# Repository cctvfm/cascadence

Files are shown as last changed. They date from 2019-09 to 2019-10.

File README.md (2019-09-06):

# cascadence
Cascadence is a low-cost eurorack-compatible Arduino development platform developed with the Modular Seattle Team.

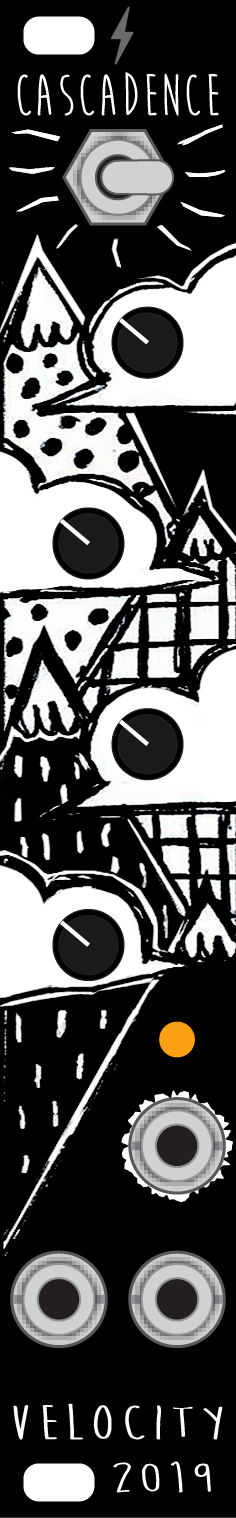
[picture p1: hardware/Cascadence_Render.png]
render


`/hardware` contains the board and panel files

`/firmware` contains the released firmwares available. You can upload new firmwares using Arduino

`/software` contains the files and instructions needed to get Cascadence working with Arduino

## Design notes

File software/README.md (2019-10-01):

# Software

This section is everything you need to upload new firmware and begin developing your own.

There are two parts that you need

1. An Arduino Board definition for the Attiny84, configured to use Micronucleus as the programmer
2. Micronucleus to communicate with the Attiny84

Please do not connect the micro usb and eurorack power at the same time, as this may cause over-current warnings on some computers.

## 1. Board Definition

Included are the group of files you need to move to the Arduino board definition folder. On Mac this is in

```~/Documents/Arduino/hardware/```

On Windows it should be in

```My Documents\Arduino\hardware```

You need to move the CCTV folder as well as it's contents. Your structure should look like:

```~/Documents/Arduino/hardware/CCTV/avr/boards.txt (etc)```

You can test that this worked by opening Arduino. Under `Tools --> Board` you should now see `CCTV - Cascadence (Attiny84 5V 8Mhz)`

This is easier to do by downloading this entire repository and unzipping.

## 2. Micronucleus

There's a few extra steps depending on what OS you're using

You need to pull the full repository from [Micronucleus Github](https://github.com/micronucleus/micronucleus). On the main Github Page for Micronucleus, click 'Clone or Download', Download Zip, then extract the Zip file on your local machine.

### OSX

First, [install homebrew](https://brew.sh/) if you haven't already

then, open a command terminal and enter:

`cd <micronucleus Directory>/commandline`

`brew install libusb-compat`

`make`

Navigate to /commandline. Copy the micronucleus executable in the commandline directory to Arduino/hardware/tools.

### Windows

 In Windows, copy  **micronucleus.exe** to Arduino/hardware/tools. **micronucleus.exe** is found in **micronucleus/commandline/builds/Windows/**
 
 Unfortunately, Windows doesn't know what to do with the micronucleus bootloader on the ATtiny84. It comes up as an Unknown USB Device, so we'll fix that with a custom driver. Lucky for us, the micronucleus project already comes with one.

 Plug in the module, and run `zadig_2.1.2.exe` as administrator.
 
 In the interface, select **Unknown Device #1** from the dropdown menu, and make sure that **libusb-win32** is selected for the driver.

 Click Install Driver and let Zadig do its thing. Close out of Zadig once the installation is complete.
 
 ### Linux
 
 Refer to [this article](https://learn.sparkfun.com/tutorials/how-to-install-an-attiny-bootloader-with-virtual-usb/all), specifically the section titled **Build the Micronucleus Loader (Linux)**

This platform was created following the excellent guide from [Sparkfun](https://learn.sparkfun.com/tutorials/how-to-install-an-attiny-bootloader-with-virtual-usb/all) and if you have any problems, or if you want to explore tweaking the bootloader or board definitions you should definitely read their write up on Attiny84 USB.

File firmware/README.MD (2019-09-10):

In this folder you will find the firmwares available for Cascadence. If you wish to submit your own firmware please get in touch with me (fil@cctv.fm).

They are all written in Arduino, and rely on tinySPI (https://github.com/JChristensen/tinySPI)

## Locking Sequencer - a dual 4 step sequencer

Clock In moves the sequencer to the next step

The 4 potentiometers adjust the pitch of each step.

Switching the toggle to the left or right enables editing of that sequencer, while the other remains unchanged

## ADSR - a dual analog modelling envelope
Simulates a capacitor charging and discharging at the attack, decay, and release stages by modelling a first-order filter

Clock in - trigger/gate to start both envelopes

Potentiometers from top to bottom - Attack, Decay, Sustain, Release

Toggle switch - changes active editing of envelope A or B.

## Euclidean Sequencer
Generates mathematically derived rhythms from a set of input conditions. 32 step.

Clock in - Trigger input

Potentiometers from top to bottom:
1. Length - the total step length of the sequence from 0 to 32
2. Density - the number of pulses to distribute in the sequence, scales from 1 to Length
3. Offset - shifts the sequence right this number of steps. Scales from 1 to Length
4. Randomness - The likelyhood of a pulse state being inverted. At full counter-clockwise, 0 randomness is added. At full clockwise every pulse will be inverted (no pulse becomes pulse, pulse becomes no pulse). In between min and max, the sequence will change at every iteration. The 'coin' is flipped every time a pulse is about to be sent out.

Toggle Switch - changes active editing of sequence A or B.

## Turing Machine

Algorithmic Sequence generator with variable probability of mutation. Implemented here with a linked pulse output and optional quantizer.

Clock in - Trigger input

Potentiometers from top to bottom:
1. Randomness - this is the big knob on the original TM. Fully clockwise and your loop is repeated, fully counter clockwise, and your loop is inverted creating a mirrored loop twice as long as the 'length' setting. In the middle is a 50% chance of mutation at every iteration
2. Length - adjustable from 1 to 16. This is the number of bits in the shift register. The output is scaled to the bit length, and the output is taken from the available bits you have set here, for example if length is 3, you get a 3 bit output scaled to the full range of the output, limited by the 'Scale' setting.
3. Scale - the range from the lowest to the highest voltage outputed. Fully clockwise is the max range, fully counter clockwise you get no output.
4. Offset - Shifts the sequence up but preserving relationships

Toggle Switch - Engages a Chromatic Quantizer. Right is quantized, Left is unquantized.

A Output - The CV sequence output

B Output - Sends a pulse if the LSB in the shift register is '1'. You can use this in conjunction with the CV sequence to create interesting patterns.

## Template

A Simple template to get you started with writing your own Cascadence code. Includes the DAC functions and pin definitions so all the hard work is done for you.

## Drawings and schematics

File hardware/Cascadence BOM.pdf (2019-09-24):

## Cascadence BOM

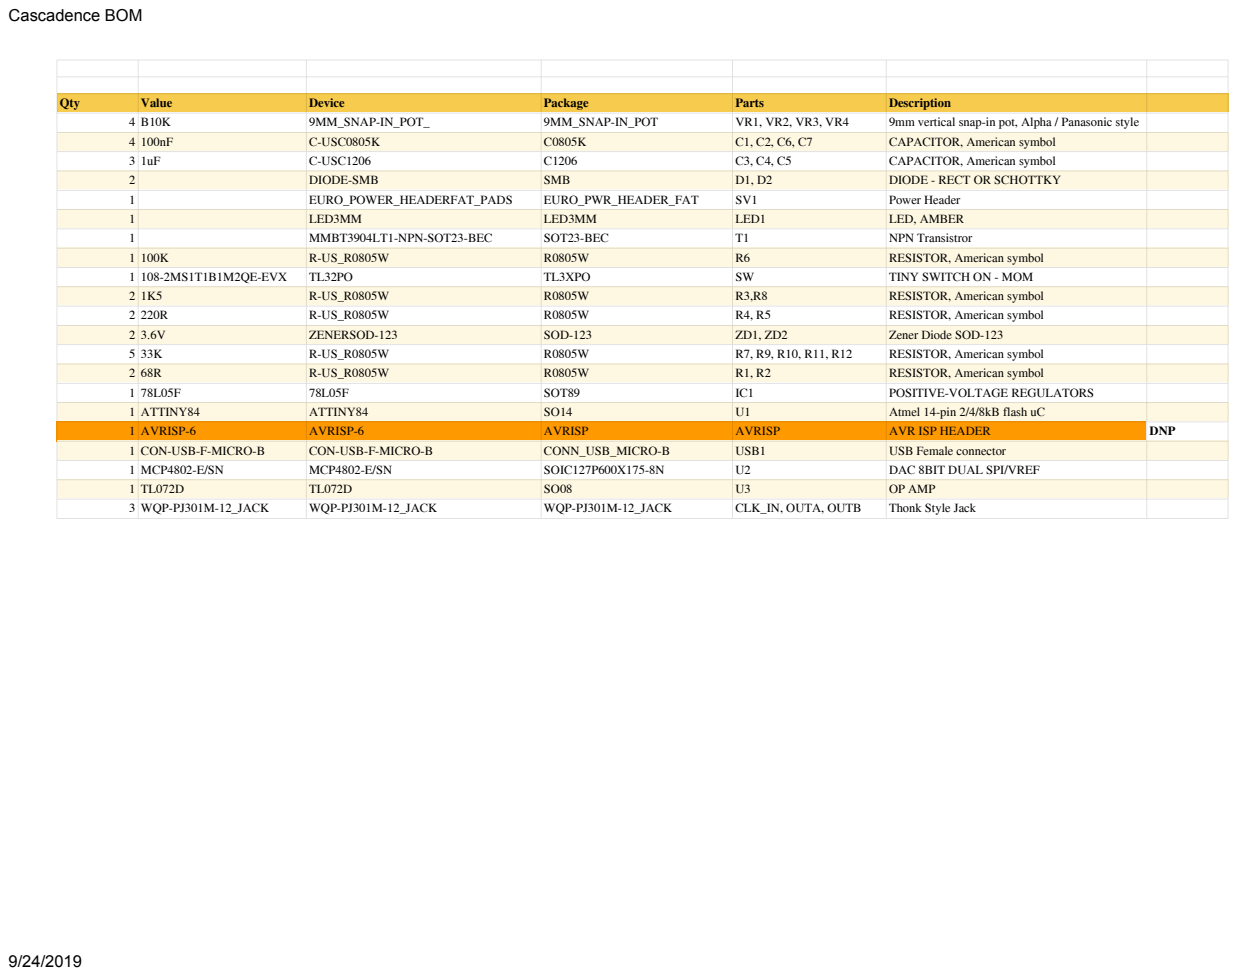
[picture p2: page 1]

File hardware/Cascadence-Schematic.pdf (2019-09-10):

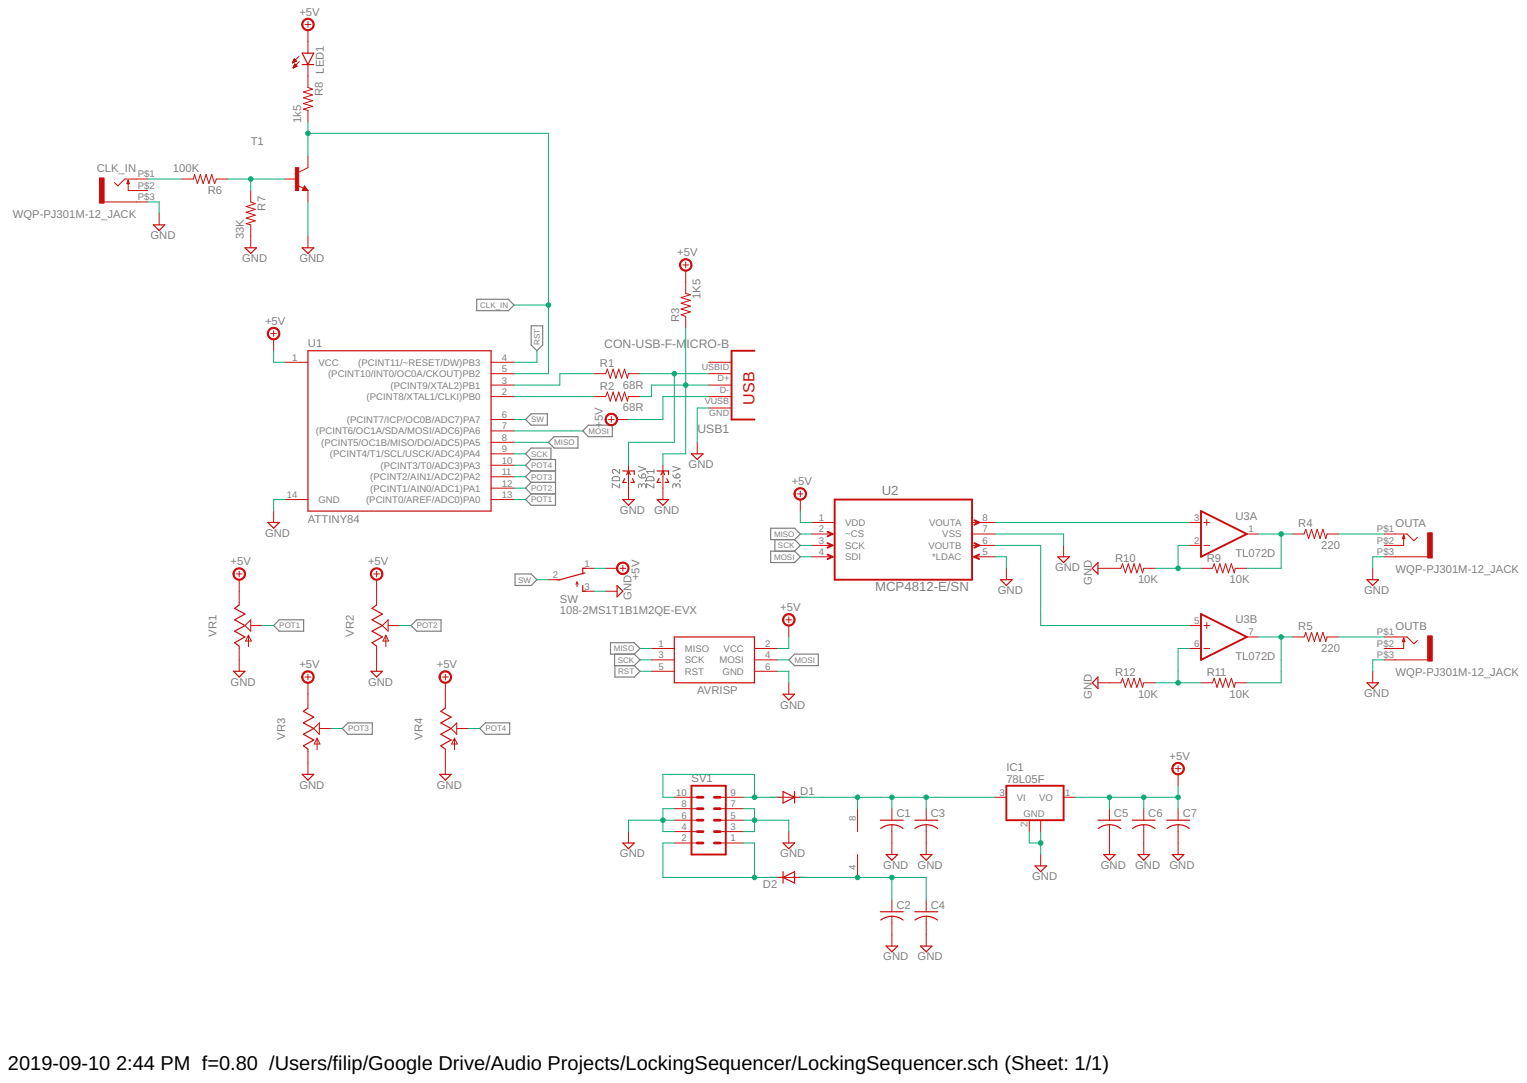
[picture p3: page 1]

2019-09-10 2:44 PM f=0.80 /Users/filip/Google Drive/Audio Projects/LockingSequencer/LockingSequencer.sch (Sheet: 1/1)

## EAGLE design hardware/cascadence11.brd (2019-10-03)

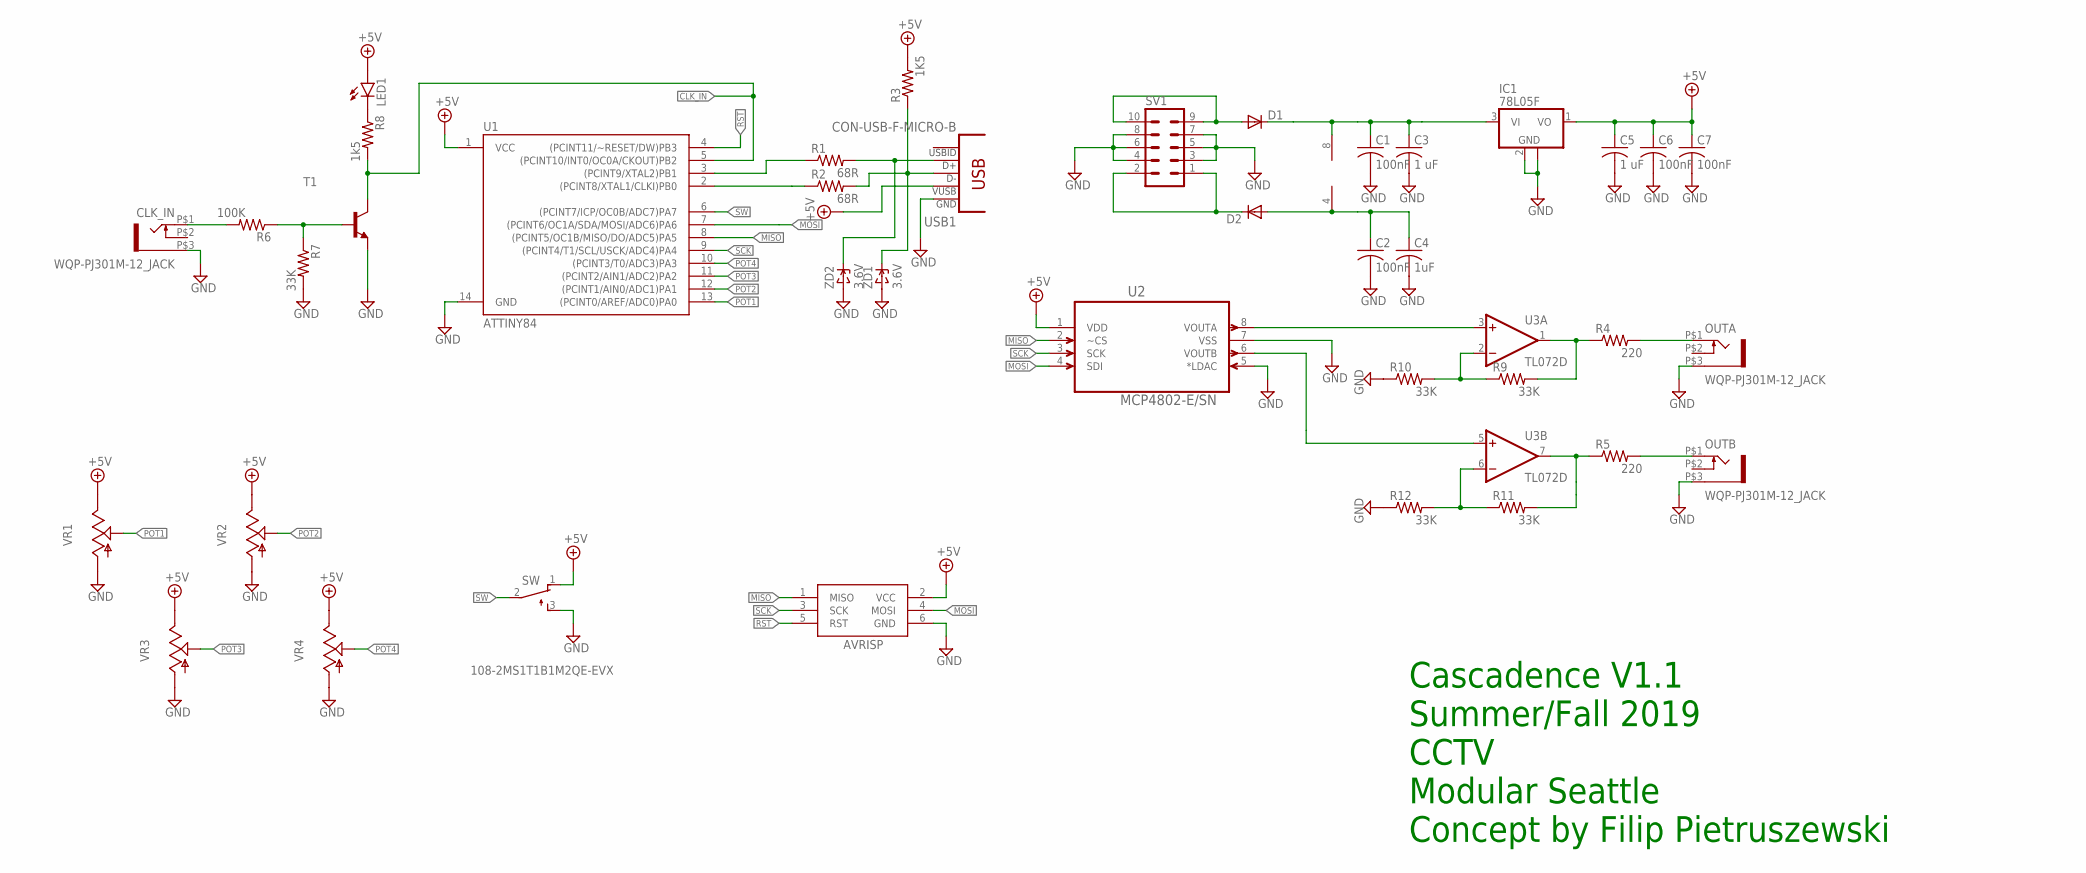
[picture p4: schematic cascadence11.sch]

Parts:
AVRISP: AVRISP-6; AVRISP
C1, C2, C6, C7: 100nF; C0805K
C3, C5: 1 uF; C1206
C4: 1uF; C1206
CLK_IN: WQP-PJ301M-12_JACK
D1, D2: DIODE-SMB; SMB
IC1: 78L05F; SOT89
LED1: LED3MM
OUTA: WQP-PJ301M-12_JACK
OUTB: WQP-PJ301M-12_JACK
R1, R2: 68R; R0805W
R3: 1K5; R0805W
R4, R5: 220; R0805W
R6: 100K; R0805W
R7, R9, R10, R11, R12: 33K; R0805W
R8: 1k5; R0805W
SV1: EURO_POWER_HEADERFAT_PADS; EURO_PWR_HEADER_FAT
SW: 108-2MS1T1B1M2QE-EVX; TL3XPO
T1: MMBT3904LT1-NPN-SOT23-BEC; SOT23-BEC
U1: ATTINY84; SO14
U2: MCP4802-E/SN; SOIC127P600X175-8N
U3: TL072D; SO08
USB1: CON-USB-F-MICRO-B; CONN_USB_MICRO-B
VR1, VR2, VR3, VR4: 9MM_SNAP-IN_POT_; 9MM_SNAP-IN_POT
ZD1, ZD2: 3.6V; SOD-123

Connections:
+5V: AVRISP.2 (VCC), C5.1, C6.1, C7.1, IC1.1 (VO), LED1.A, R3.2, SW.1 (O), U1.1 (VCC), U2.1 (VDD), USB1.P1 (VUSB), VR1.3 (E), VR2.3 (E), VR3.3 (E), VR4.3 (E)
CLK_IN: R8.2, T1.C, U1.5 ((PCINT10/INT0/OC0A/CKOUT)PB2)
GND: AVRISP.6 (GND), C1.2, C2.2, C3.2, C4.2, C5.2, C6.2, C7.2, CLK_IN.P$3 (1), IC1.2 (GND), IC1.2@1 (GND), OUTA.P$3 (1), OUTB.P$3 (1), R7.2, R10.1, R12.1, SV1.3, SV1.4, SV1.5, SV1.6, SV1.7, SV1.8, SW.3 (S), T1.E, U1.14 (GND), U2.5 (*LDAC), U2.7 (VSS), USB1.P5 (GND), VR1.1 (A), VR2.1 (A), VR3.1 (A), VR4.1 (A), ZD1.A, ZD2.A
MISO: AVRISP.1 (MISO), U1.8 ((PCINT5/OC1B/MISO/DO/ADC5)PA5), U2.2 (~CS)
MOSI: AVRISP.4 (MOSI), U1.7 ((PCINT6/OC1A/SDA/MOSI/ADC6)PA6), U2.4 (SDI)
unnamed: R1.2, USB1.P3 (D+), ZD2.C
unnamed: R2.2, R3.1, USB1.P2 (D-), ZD1.C
unnamed: R2.1, U1.2 ((PCINT8/XTAL1/CLKI)PB0)
unnamed: U2.8 (VOUTA), U3.3 (+IN)
unnamed: R1.1, U1.3 ((PCINT9/XTAL2)PB1)
unnamed: D2.C, SV1.1, SV1.2
unnamed: U2.6 (VOUTB), U3.5 (+IN)
unnamed: R4.1, R9.2, U3.1 (OUT)
unnamed: R5.1, R11.2, U3.7 (OUT)
unnamed: CLK_IN.P$1 (2), R6.2
unnamed: OUTA.P$1 (2), R4.2
unnamed: OUTB.P$1 (2), R5.2
unnamed: R6.1, R7.1, T1.B
unnamed: C2.1, C4.1, D2.A, U3.4 (V-)
unnamed: LED1.K (C), R8.1
unnamed: D1.A, SV1.9, SV1.10
unnamed: C1.1, C3.1, D1.C, IC1.3 (VI), U3.8 (V+)
unnamed: R9.1, R10.2, U3.2 (-IN)
unnamed: R11.1, R12.2, U3.6 (-IN)
POT1: U1.13 ((PCINT0/AREF/ADC0)PA0), VR1.2 (S)
POT2: U1.12 ((PCINT1/AIN0/ADC1)PA1), VR2.2 (S)
POT3: U1.11 ((PCINT2/AIN1/ADC2)PA2), VR3.2 (S)
POT4: U1.10 ((PCINT3/T0/ADC3)PA3), VR4.2 (S)
RST: AVRISP.5 (RST), U1.4 ((PCINT11/~RESET/DW)PB3)
SCK: AVRISP.3 (SCK), U1.9 ((PCINT4/T1/SCL/USCK/ADC4)PA4), U2.3 (SCK)
SW: SW.2, U1.6 ((PCINT7/ICP/OC0B/ADC7)PA7)

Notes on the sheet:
Cascadence V1.1 Summer/Fall 2019 CCTV Modular Seattle Concept by Filip Pietruszewski

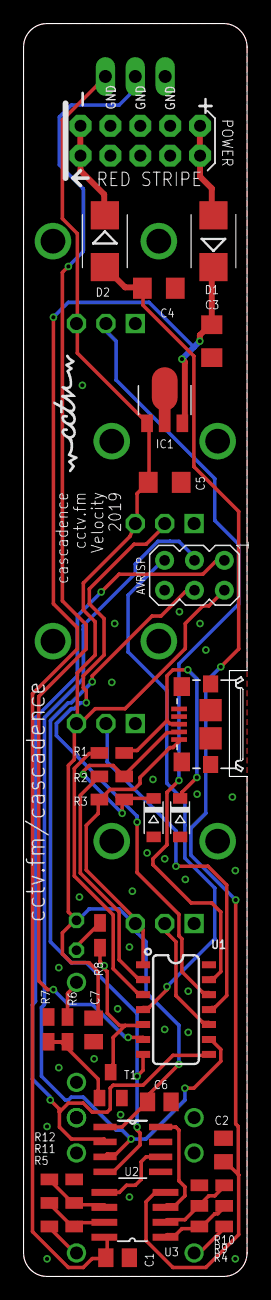
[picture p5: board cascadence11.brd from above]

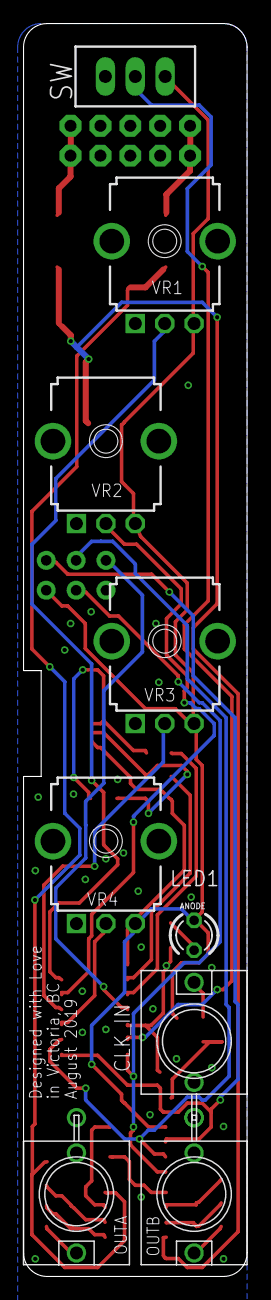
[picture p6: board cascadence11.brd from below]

Board: 2 copper layers, 19.0 x 106.5 mm, 40 parts (9 on the bottom side), 31 nets.

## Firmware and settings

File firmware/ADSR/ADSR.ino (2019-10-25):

// Cascadence ADSR
// Based on
// ADSRduino
// https://github.com/m0xpd/ADSRduino
// a simple ADSR for the Arduino
// m0xpd
// Feb 2017
//
// see http://m0xpd.blogspot.co.uk/2017/02/signal-processing-on-arduino.html
//
//
//
// https://github.com/cctvfm/cascadence/




const int GAIN_1 = 0x1;
const int GAIN_2 = 0x0;
const int NO_SHTDWN = 1;
const int SHTDWN = 0;

//pin definitions
const int POTS[4]={0,1,2,3};
const int gatePin = 8;
const int CLK_IN = 8;
const int SW = 7;

const int MOSI = 6;
const int SCK = 4;
const int PIN_CS = 5;

const int A = 0;
const int B = 1;

unsigned int lastanalogread[4];

float alpha[2]={0.7,0.7};   // this is the pole location ('time constant') used for the first-order difference equation
double alpha1[2]={0.9,0.9};  // initial value for attack
double alpha2[2]={0.9,0.9};  // initial value for decay
double alpha3[2]={0.95,0.95}; // initial value for release

float envelope[2] = {0.0,0.0};  // initialise the envelope
float CV0[2] = {0.0,0.0};       // result of reads from potentiometers (yes - it will only be an int, but helps with the casting!)
float CV1[2] = {0.0,0.0};
int CV2[2] = {0,0};
float CV3[2] = {0.0,0.0};

int drive[2] = {0,0};
int sustain_Level[2] = {0,0};
int scan = 0;
boolean note_active[2] = {false,false};
boolean loop_mode=false;
boolean trigger = false;
boolean decay[2] = {false,false};
boolean release_done[2] = {true,true};


void update_params(int scan, boolean chan);

// subroutine to set DAC on MCP4802
void setOutput(byte channel, byte gain, byte shutdown, unsigned int val)
{
  byte lowByte = val & 0xff;
  byte highByte = ((val >> 8) & 0xff) | channel << 7 | gain << 5 | shutdown << 4;
  //bit level stuff to make the dac work.
  //channel can be 0 or 1 (A or B)
  //gain can be 0 or 1 (x1 or x2 corresponding to 2V max or 4V max)
  //shutdown is to disable the DAC output, 0 for shutdown, 1 for no shutdown
   
  digitalWrite(PIN_CS, LOW);
  shiftOut(MOSI,SCK,MSBFIRST,highByte);
  shiftOut(MOSI,SCK,MSBFIRST,lowByte);
  digitalWrite(PIN_CS, HIGH);
}
void setup() {
  
unsigned int x;

  pinMode(POTS[0], INPUT);
  pinMode(POTS[1], INPUT);
  pinMode(POTS[2], INPUT);
  pinMode(POTS[3], INPUT);
  pinMode(SW, INPUT);
  pinMode(CLK_IN,INPUT_PULLUP);


//mosi, sck, and pin_cs used for spi dac (mcp4822)
  pinMode(MOSI,OUTPUT);
  pinMode(SCK,OUTPUT);
  
  
  digitalWrite(PIN_CS,HIGH);
  pinMode(PIN_CS, OUTPUT);

  for(x=0;x<4;x++)
  {
    update_params(x,A); //initialize CVs
    update_params(x,B); //initialize CVs

  }

  setOutput(A, GAIN_2, NO_SHTDWN, 0);
  setOutput(B, GAIN_2, NO_SHTDWN, 0);


}

void loop() {
    boolean gate=!digitalRead(gatePin);        // read the gate input every time through the loop
    checkforchange(scan);                     // scan only one of the other inputs each pass 
    
    boolean trigger=gate||(loop_mode&&release_done);  // trigger a, ADSR even if there's a gate OR if we're in loop mode
    while(trigger){  
      if(note_active[A]==false){                   // if a note isn't active and we're triggered, then start one!
      decay[A] = false;
      drive[A]=4096;                               // drive toward full value
      alpha[A]=alpha1[A];                             // set 'time constant' alpha1 for attack phase 
      note_active[A]=true;                         // set the note_active flag
      } 
      if(note_active[B]==false){                   // if a note isn't active and we're triggered, then start one!
      decay[B] = false;
      drive[B]=4096;                               // drive toward full value
      alpha[B]=alpha1[B];                             // set 'time constant' alpha1 for attack phase 
      note_active[B]=true;                         // set the note_active flag
      }
      
      if((decay[A]==false)&&(envelope[A]>4000)&&(drive[A]==4096)){    // if we've reached envelope >4000 with drive= 4096, we must be at the end of attack phase
                                                          // so switch to decay...
        decay[A] = true;                                         // set decay flag
        drive[A]=sustain_Level[A];                                  // drive toward sustain level
        alpha[A]=alpha2[A];                                         // and set 'time constant' alpha2 for decay phase
      } 
      if((decay[B]==false)&&(envelope[B]>4000)&&(drive[B]==4096)){    // if we've reached envelope >4000 with drive= 4096, we must be at the end of attack phase
                                                          // so switch to decay...
        decay[B] = true;                                         // set decay flag
        drive[B]=sustain_Level[B];                                  // drive toward sustain level
        alpha[B]=alpha2[B];                                         // and set 'time constant' alpha2 for decay phase
      }
  
      envelope[A]=((1.0-alpha[A])*drive[A]+alpha[A]*envelope[A]);     // implement difference equation: y(k) = (1 - alpha) * x(k) + alpha * y(k-1)
      envelope[B]=((1.0-alpha[B])*drive[B]+alpha[B]*envelope[B]);
      setOutput(A, GAIN_2, NO_SHTDWN, (round(envelope[A])));                   // and output the envelope to the DAC
      setOutput(B, GAIN_2, NO_SHTDWN, (round(envelope[B]))); 
     

    gate=!digitalRead(gatePin);                      // read the gate pin (remember we're in the while loop)
    trigger=gate||(loop_mode&&release_done);        // and re-evaluate the trigger function
    }
    
    if(note_active[A]==true){                // this is the start of the release phase
      drive[A]=0;                              // drive towards zero
      alpha[A]=alpha3[A];                         // set 'time comnstant' alpha3 for release phase
      note_active[A]=false;                    // turn off note_active flag
      release_done[A]=false;                   // and set release_flag done false
    }   
    if(note_active[B]==true){                // this is the start of the release phase
      drive[B]=0;                              // drive towards zero
      alpha[B]=alpha3[B];                         // set 'time comnstant' alpha3 for release phase
      note_active[B]=false;                    // turn off note_active flag
      release_done[B]=false;                   // and set release_flag done false
    }   
  
    envelope[A]=((1.0-alpha3[A])*drive[A]+alpha3[A]*envelope[A]);   // implement the difference equation again (outside the while loop)
    setOutput(A, GAIN_2, NO_SHTDWN, (round(envelope[A])));                    // and output envelope
    envelope[B]=((1.0-alpha3[B])*drive[B]+alpha3[B]*envelope[B]);   // implement the difference equation again (outside the while loop)
    setOutput(B, GAIN_2, NO_SHTDWN, (round(envelope[B])));                    // and output envelope
    gate=!digitalRead(gatePin);                       // watch out for a new note
    scan+=1;                                         // prepare to look at a new parameter input
    if(envelope[A]<4){                                  // is the release phase ended?
      release_done[A]=true;                             // yes - so flag it
    }
    if(envelope[B]<4){                                  // is the release phase ended?
      release_done[B]=true;                             // yes - so flag it
    }
    if(scan==5){                                     // increment the scan pointer
      scan=0;
    }
}

void checkforchange (int scan)
{
  unsigned int tempread[4];
  unsigned char x;
  #define THRESHOLD 5
  
    tempread[scan]=analogRead(scan);
    if(tempread[scan]<(lastanalogread[scan]-THRESHOLD) || tempread[scan]>(lastanalogread[scan]+THRESHOLD))
    {
      //knob has been moved while we're on this channel, update it.
      update_params(scan,!digitalRead(SW));
      lastanalogread[scan]=tempread[scan];
      
    }
  
  
}

void update_params(int scan, boolean chan){             // read the input parameters
  switch (scan){
  case 0:
  CV0[chan]=analogRead(0);                      // get the attack pole location
  alpha1[chan]=0.999*cos((1023-CV0[chan])/795);
  alpha1[chan]=sqrt(alpha1[chan]);  
  break;
  case 1:
  CV1[chan]=analogRead(1);                      // get the release pole location
  alpha2[chan]=0.999*cos((1023-CV1[chan])/795);
  alpha2[chan]=sqrt(alpha2[chan]);   
  break; 
  case 2:
  CV2[chan]=analogRead(2);                     // get the (integer) sustain level
  sustain_Level[chan]=CV2[chan]<<2;
  break;
  case 3:
  CV3[chan]=analogRead(3);                     // get the release pole location (potentially closer to 1.0)
  alpha3[chan]=0.99999*cos((1023-CV3[chan])/795);
  alpha3[chan]=sqrt(alpha3[chan]);
  break;  
 
  
  }
  
}

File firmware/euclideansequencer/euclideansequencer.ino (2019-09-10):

#include <tinySPI.h>

//Euclidean Sequencer
//For Cascadence
//Developed with Modular Seattle for Velocity 2019

//euclid function modified from Tom Whitwell's amazing euclidean sequencer
//https://github.com/TomWhitwell/Euclidean-sequencer
    
#define MAXSTEPLENGTH 31  //+1 because 0 is a step = 32 is the step length
const int GAIN_1 = 0x1;
const int GAIN_2 = 0x0;
const int NO_SHTDWN = 1;
const int SHTDWN = 0;

//pin definitions
const int POTS[4]={0,1,2,3};

const int CLK_IN = 8;
const int SW = 7;

const int MOSI = 6;
const int SCK = 4;
const int PIN_CS = 5;

unsigned int values[2][4];
const int A = 0;
const int B = 1;
long int euclids[2];
unsigned char stepnumber=0;
unsigned char offset_stepnumber[2];
unsigned char seq_length[2];
unsigned char seq_offset[2];
unsigned char seq_density[2];
unsigned char seq_randomness[2];
void setup()
{


  pinMode(POTS[0], INPUT);
  pinMode(POTS[1], INPUT);
  pinMode(POTS[2], INPUT);
  pinMode(POTS[3], INPUT);
  pinMode(SW, INPUT);
  pinMode(CLK_IN,INPUT_PULLUP);


//mosi, sck, and pin_cs used for spi dac (mcp4822)
  pinMode(MOSI,OUTPUT);
  pinMode(SCK,OUTPUT);
  
  
  digitalWrite(PIN_CS,HIGH);
  pinMode(PIN_CS, OUTPUT);


  updatevalues[A];
  updatevalues[B];
  
}

void loop() {
int pulse = false;
while(1)
{
  
  if(digitalRead(CLK_IN) == LOW)  //we've received a clock pulse!
    {
      //calculate the actual step number for each sequencer
      offset_stepnumber[A]=stepnumber+seq_offset[A];
      if(offset_stepnumber[A]>=seq_length[A])
        offset_stepnumber[A]=offset_stepnumber[A] % seq_length[A];
        
      offset_stepnumber[B]=stepnumber+seq_offset[B];
      if(offset_stepnumber[B]>=seq_length[B])
        offset_stepnumber[B]=offset_stepnumber[B] % seq_length[B];
      
      pulse=false;
      if(bitRead(euclids[A],offset_stepnumber[A]) == 1) //if there's a pulse
        pulse=true;

      if (random(MAXSTEPLENGTH) <= seq_randomness[A] )  //or if there's a randomly generated pulse
        pulse = !pulse;
      if(pulse==1)  
        SendPulse(A); //send one

      pulse=false;
      if(bitRead(euclids[B],offset_stepnumber[B]) == 1) //if there's a pulse
        pulse = true;
      if (random(MAXSTEPLENGTH) <= seq_randomness[B] )
        pulse = !pulse;
      if(pulse == 1)
        SendPulse(B); //send one
      
      stepnumber++;
      if(stepnumber>MAXSTEPLENGTH)
      {
        stepnumber = 0;
      }
      while(digitalRead(CLK_IN) == LOW);
      
    }
    

    updatevalues(!digitalRead(SW));
}
}

// Euclid calculation function 
//Borrowed lovingly from TomWhitwell
//https://github.com/TomWhitwell/Euclidean-sequencer

uint64_t euclid(int n, int k){ // inputs: n=total, k=beats, o = offset
  int pauses = n-k;
  int pulses = k;
  int per_pulse = pauses/k;
  int remainder = pauses%pulses;  
  long int workbeat[n];
  long int outbeat;
  long int working;
  int workbeat_count=n;
  int a; 
  int b; 
  int trim_count;
  for (a=0;a<n;a++){ // Populate workbeat with unsorted pulses and pauses 
    if (a<pulses){
      workbeat[a] = 1;
    }
    else {
      workbeat [a] = 0;
    }
  }

  if (per_pulse>0 && remainder <2){ // Handle easy cases where there is no or only one remainer  
    for (a=0;a<pulses;a++){
      for (b=workbeat_count-1; b>workbeat_count-per_pulse-1;b--){
        workbeat[a]  = ConcatBin (workbeat[a], workbeat[b]);
      }
      workbeat_count = workbeat_count-per_pulse;
    }

    outbeat = 0; // Concatenate workbeat into outbeat - according to workbeat_count 
    for (a=0;a < workbeat_count;a++){
      outbeat = ConcatBin(outbeat,workbeat[a]);
    }
    return outbeat;
  }

  else { 


    int groupa = pulses;
    int groupb = pauses; 
    int iteration=0;
    if (groupb<=1){
    }
    while(groupb>1){ //main recursive loop


      if (groupa>groupb){ // more Group A than Group B
        int a_remainder = groupa-groupb; // what will be left of groupa once groupB is interleaved 
        trim_count = 0;
        for (a=0; a<groupa-a_remainder;a++){ //count through the matching sets of A, ignoring remaindered
          workbeat[a]  = ConcatBin (workbeat[a], workbeat[workbeat_count-1-a]);
          trim_count++;
        }
        workbeat_count = workbeat_count-trim_count;

        groupa=groupb;
        groupb=a_remainder;
      }


      else if (groupb>groupa){ // More Group B than Group A
        int b_remainder = groupb-groupa; // what will be left of group once group A is interleaved 
        trim_count=0;
        for (a = workbeat_count-1;a>=groupa+b_remainder;a--){ //count from right back through the Bs
          workbeat[workbeat_count-a-1] = ConcatBin (workbeat[workbeat_count-a-1], workbeat[a]);

          trim_count++;
        }
        workbeat_count = workbeat_count-trim_count;
        groupb=b_remainder;
      }




      else if (groupa == groupb){ // groupa = groupb 
        trim_count=0;
        for (a=0;a<groupa;a++){
          workbeat[a] = ConcatBin (workbeat[a],workbeat[workbeat_count-1-a]);
          trim_count++;
        }
        workbeat_count = workbeat_count-trim_count;
        groupb=0;
      }

      else {
        //        Serial.println("ERROR");
      }
      iteration++;
    }


    outbeat = 0; // Concatenate workbeat into outbeat - according to workbeat_count 
    for (a=0;a < workbeat_count;a++){
      outbeat = ConcatBin(outbeat,workbeat[a]);
    }




    return outbeat;

  }
}
void updatevalues(boolean chan)
{
  unsigned char x;
   for(x=0;x<4;x++)
  {
    values[chan][x]=analogRead(POTS[x]);  //read the 4 pots so we don't have junk for the first sequence
  }

  seq_length[chan]=map(values[chan][0],0,1023,1,MAXSTEPLENGTH+1);
  seq_density[chan]=map(values[chan][1],0,1023,1,seq_length[chan]);
  seq_offset[chan]=map(values[chan][2],0,1023,0,seq_length[chan]);
  seq_randomness[chan]=map(values[chan][3],0,1023,0,MAXSTEPLENGTH);

  if(seq_density[chan]>seq_length[chan])
    seq_density[chan]=seq_length[chan];
  euclids[chan]=euclid(seq_length[chan],seq_density[chan]);
}

void SendPulse (boolean chan)
{
  setOutput(chan, GAIN_2, NO_SHTDWN, 0xFFF);
  delay(40);
  setOutput(chan, GAIN_2, NO_SHTDWN, 0);
}
void setOutput(byte channel, byte gain, byte shutdown, unsigned int val)
{
  byte lowByte = val & 0xff;
  byte highByte = ((val >> 8) & 0xff) | channel << 7 | gain << 5 | shutdown << 4;
  //bit level stuff to make the dac work.
  //channel can be 0 or 1 (A or B)
  //gain can be 0 or 1 (x1 or x2 corresponding to 2V max or 4V max)
  //shutdown is to disable the DAC output, 0 for shutdown, 1 for no shutdown
   
  digitalWrite(PIN_CS, LOW);
  shiftOut(MOSI,SCK,MSBFIRST,highByte);
  shiftOut(MOSI,SCK,MSBFIRST,lowByte);
  digitalWrite(PIN_CS, HIGH);
}

// Function to concatenate two binary numbers bitwise 
long int ConcatBin(uint64_t bina, uint64_t binb){
  int binb_len=findlength(binb);
  long int sum=(bina<<binb_len);
  sum = sum | binb;
  return sum;
}
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

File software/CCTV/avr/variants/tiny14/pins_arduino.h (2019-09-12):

/*
  pins_arduino.c - pin definitions for the Arduino board
  Part of Arduino / Wiring Lite

  Copyright (c) 2005 David A. Mellis

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
  $Id: pins_arduino.c 565 2009-03-25 10:50:00Z dmellis $

  Modified 28-08-2009 for attiny84 R.Wiersma
  Modified 09-10-2009 for attiny45 A.Saporetti
*/

#ifndef Pins_Arduino_h
#define Pins_Arduino_h

#include <avr/pgmspace.h>

// ATMEL ATTINY84 / ARDUINO
//
//                           +-\/-+
//                     VCC  1|    |14  GND
//             (D 10)  PB0  2|    |13  AREF (D  0)
//             (D  9)  PB1  3|    |12  PA1  (D  1)
//                     PB3  4|    |11  PA2  (D  2)
//  PWM  INT0  (D  8)  PB2  5|    |10  PA3  (D  3)
//  PWM        (D  7)  PA7  6|    |9   PA4  (D  4)
//  PWM        (D  6)  PA6  7|    |8   PA5  (D  5)        PWM
//                           +----+

const static uint8_t A0 = 0;
const static uint8_t A1 = 1;
const static uint8_t A2 = 2;
const static uint8_t A3 = 3;
const static uint8_t A4 = 4;
const static uint8_t A5 = 5;
const static uint8_t A6 = 6;
const static uint8_t A7 = 7;

#define digitalPinToPCICR(p)    ( ((p) >= 0 && (p) <= 10) ? (&GIMSK) : ((uint8_t *)0) )
#define digitalPinToPCICRbit(p) ( ((p) <= 7) ? PCIE0 : PCIE1 )
#define digitalPinToPCMSK(p)    ( ((p) <= 7) ? (&PCMSK0) : (((p) <= 10) ? (&PCMSK1) : ((uint8_t *)0)) )
#define digitalPinToPCMSKbit(p) ( ((p) <= 7) ? (p) : (10 - (p)) )

#ifdef ARDUINO_MAIN

// these arrays map port names (e.g. port B) to the
// appropriate addresses for various functions (e.g. reading
// and writing)
const uint16_t PROGMEM port_to_mode_PGM[] =
{
  NOT_A_PORT,
  (uint16_t)&DDRA,
  (uint16_t)&DDRB,
};

const uint16_t PROGMEM port_to_output_PGM[] =
{
  NOT_A_PORT,
  (uint16_t)&PORTA,
  (uint16_t)&PORTB,
};

const uint16_t PROGMEM port_to_input_PGM[] =
{
  NOT_A_PORT,
  (uint16_t)&PINA,
  (uint16_t)&PINB,
};

const uint8_t PROGMEM digital_pin_to_port_PGM[] =
{
  PA, /* 0 */
  PA,
  PA,
  PA,
  PA,
  PA,
  PA,
  PA,
  PB, /* 8 */
  PB,
  PB,
};

const uint8_t PROGMEM digital_pin_to_bit_mask_PGM[] =
{
  _BV(0), /* port A */
  _BV(1),
  _BV(2),
  _BV(3),
  _BV(4),
  _BV(5),
  _BV(6),
  _BV(7),
  _BV(2), /* port B */
  _BV(1),
  _BV(0),
};

const uint8_t PROGMEM digital_pin_to_timer_PGM[] =
{
  NOT_ON_TIMER,
  NOT_ON_TIMER,
  NOT_ON_TIMER,
  NOT_ON_TIMER,
  NOT_ON_TIMER,
  TIMER1B, /* OC1B */
  TIMER1A, /* OC1A */
  TIMER0B, /* OC0B */
  TIMER0A, /* OC0A */
  NOT_ON_TIMER,
  NOT_ON_TIMER,
};

#endif

#endif

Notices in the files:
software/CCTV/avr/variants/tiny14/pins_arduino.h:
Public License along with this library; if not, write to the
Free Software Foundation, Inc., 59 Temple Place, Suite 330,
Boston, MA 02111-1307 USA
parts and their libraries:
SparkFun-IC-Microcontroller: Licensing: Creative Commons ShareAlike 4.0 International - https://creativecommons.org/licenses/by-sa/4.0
